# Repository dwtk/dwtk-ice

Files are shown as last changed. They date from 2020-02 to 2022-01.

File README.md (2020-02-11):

# dwtk-ice

An USB-connected In-Circuit Emulator for [dwtk](https://github.com/rafaelmartins/dwtk).

## Hardware

### Schematics

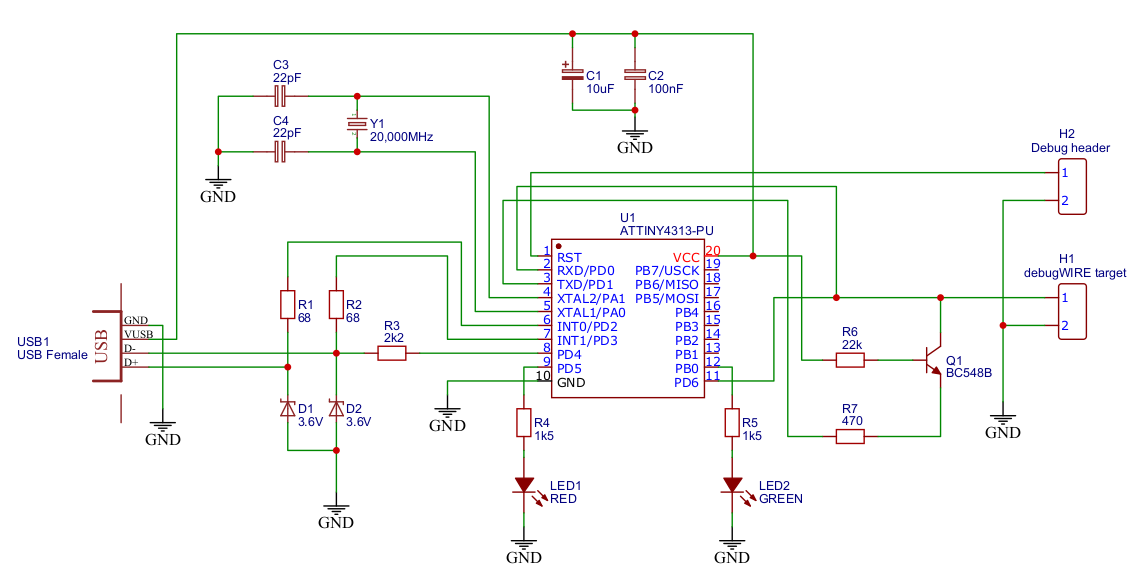
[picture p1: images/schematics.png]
dwtk-ice schematics


#### Bill of materials

ID | Description | Reichelt Item no.
-- | ----------- | -----------------
U1 | ATtiny4313 | ATTINY 4313 PU
Q1 | BC548B | BC 548B
Y1 | Crystal 20,000MHz | 20,0000-HC49U-S
D1, D2 | Zener diode 3,6V | ZF 3,6
LED1 | LED Red 5mm | LED 5MM RT
LED2 | LED Green 5mm | LED 5MM GN
C1 | Electrolytic capacitor 10uF/35V | RAD 10/35
C2 | Multi-layer ceramic capacitor 100nF | X7R-5 100N
C3, C4 | Ceramic capacitor 22pF | KERKO 22P
R1, R2 | Carbon film resistor 1/4 W, 5%, 68 Ohm| 1/4W 68
R3 | Carbon film resistor 1/4 W, 5%, 2,2K Ohm | 1/4W 2,2K
R4, R5 | Carbon film resistor 1/4 W, 5%, 1,5K Ohm | 1/4W 1,5K
R6 | Carbon film resistor 1/4 W, 5%, 22K Ohm | 1/4W 22K
R7 | Carbon film resistor 1/4 W, 5%, 470 Ohm | 1/4W 470
USB1 | USB panel socket, type A | RND 205-00660
H1 + H2 | Header pins 1x40 | SL 1X40G 2,54
&nbsp; | IC socket, 20-pin | GS 20
&nbsp; | Prototype PCB 3cm x 7cm | &nbsp;

### Prototype

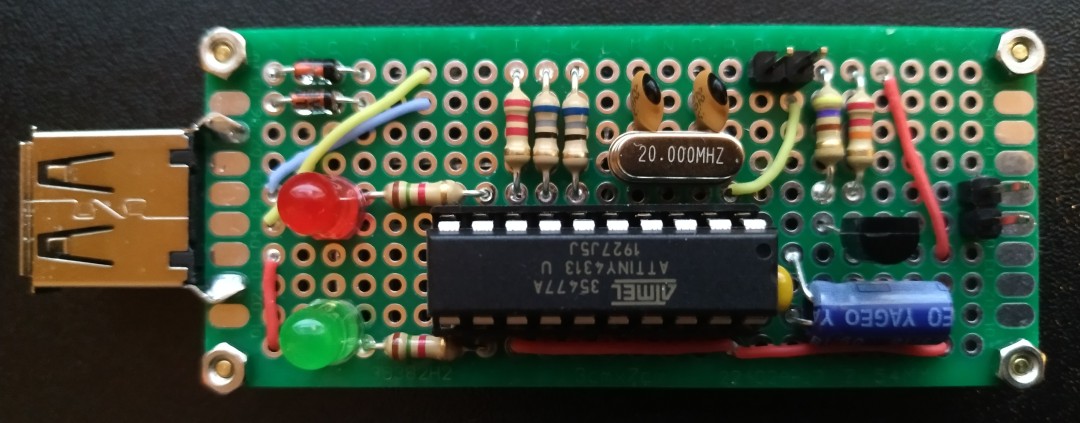
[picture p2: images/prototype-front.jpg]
dwtk-ice prototype front


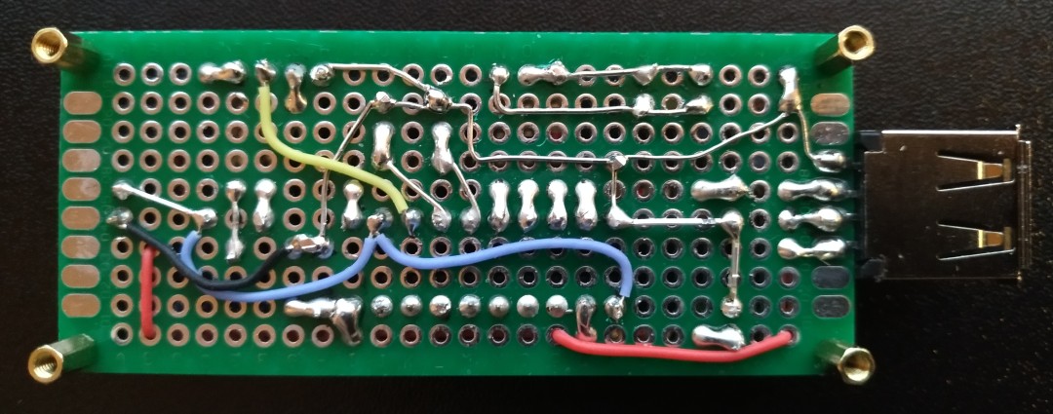
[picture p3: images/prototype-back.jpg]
dwtk-ice prototype back


### DISCLAIMER

THIS PROJECT IS PROVIDED AS IS. USE IT AT YOUR OWN RISK. THIS DEVICE IS USB CONNECTED AND MAY DAMAGE YOUR COMPUTER.

The USB connections in the schematics are there just for reference, please check the actual pinout of your connector before assembling and/or using.

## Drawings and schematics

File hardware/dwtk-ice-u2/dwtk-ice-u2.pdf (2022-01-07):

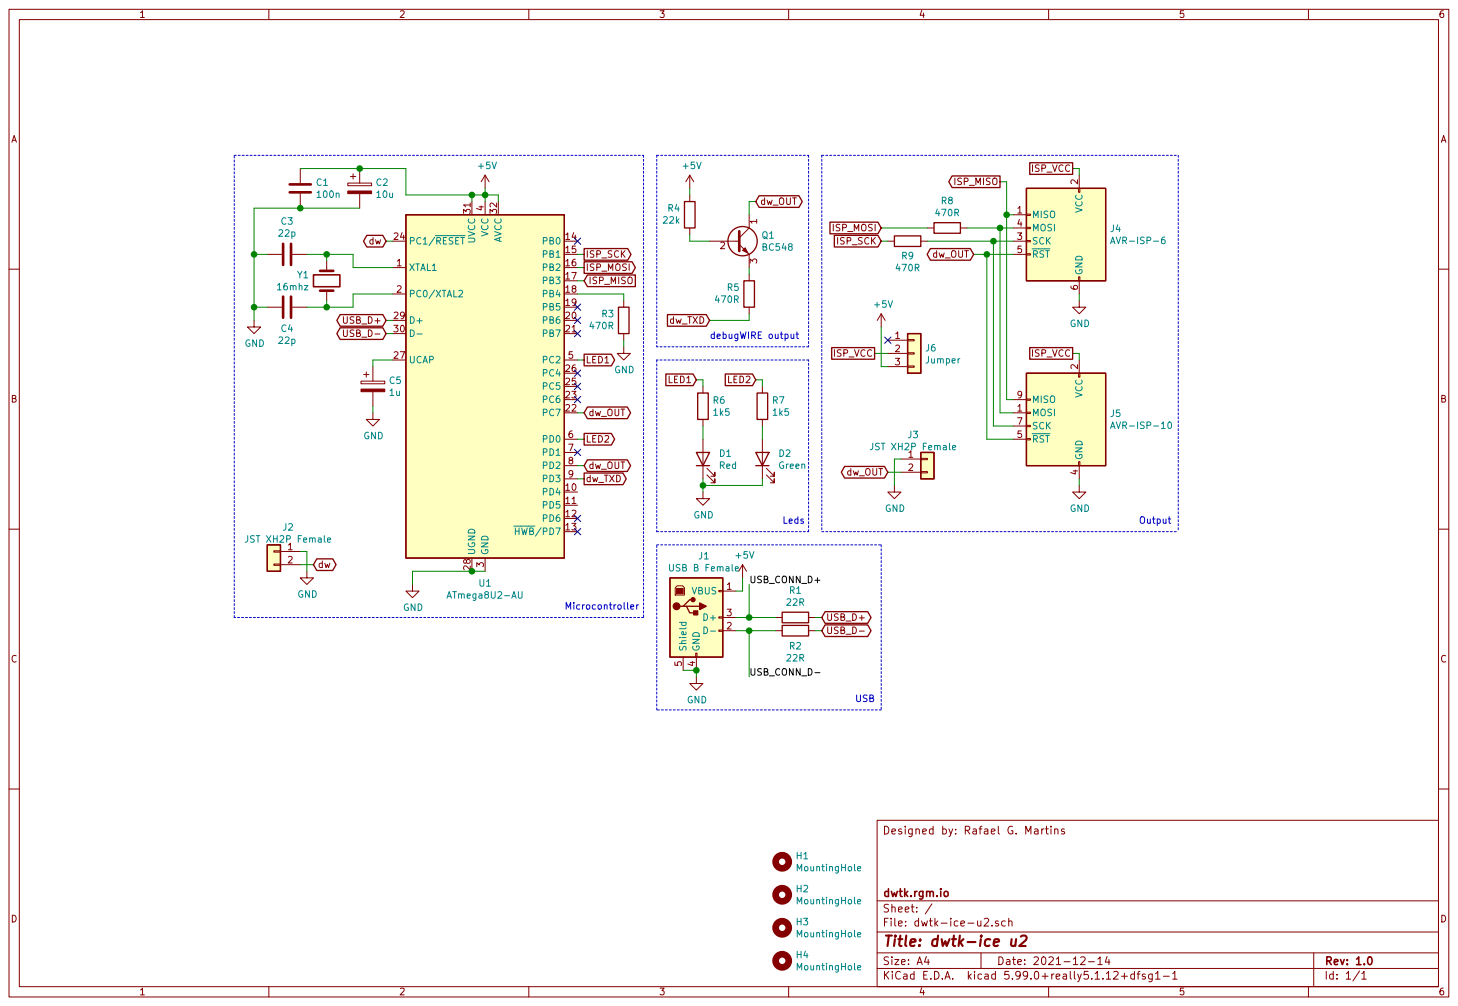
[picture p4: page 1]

2 SCK 3 MOSI 4 RST 5 GND

Designed by: Rafael G. Martins
H4MountingHole H3MountingHole H2MountingHole H1MountingHole

File: dwtk-ice-u2.sch Sheet: / dwtk.rgm.io

Id: 1/1 Title: dwtk-ice u2

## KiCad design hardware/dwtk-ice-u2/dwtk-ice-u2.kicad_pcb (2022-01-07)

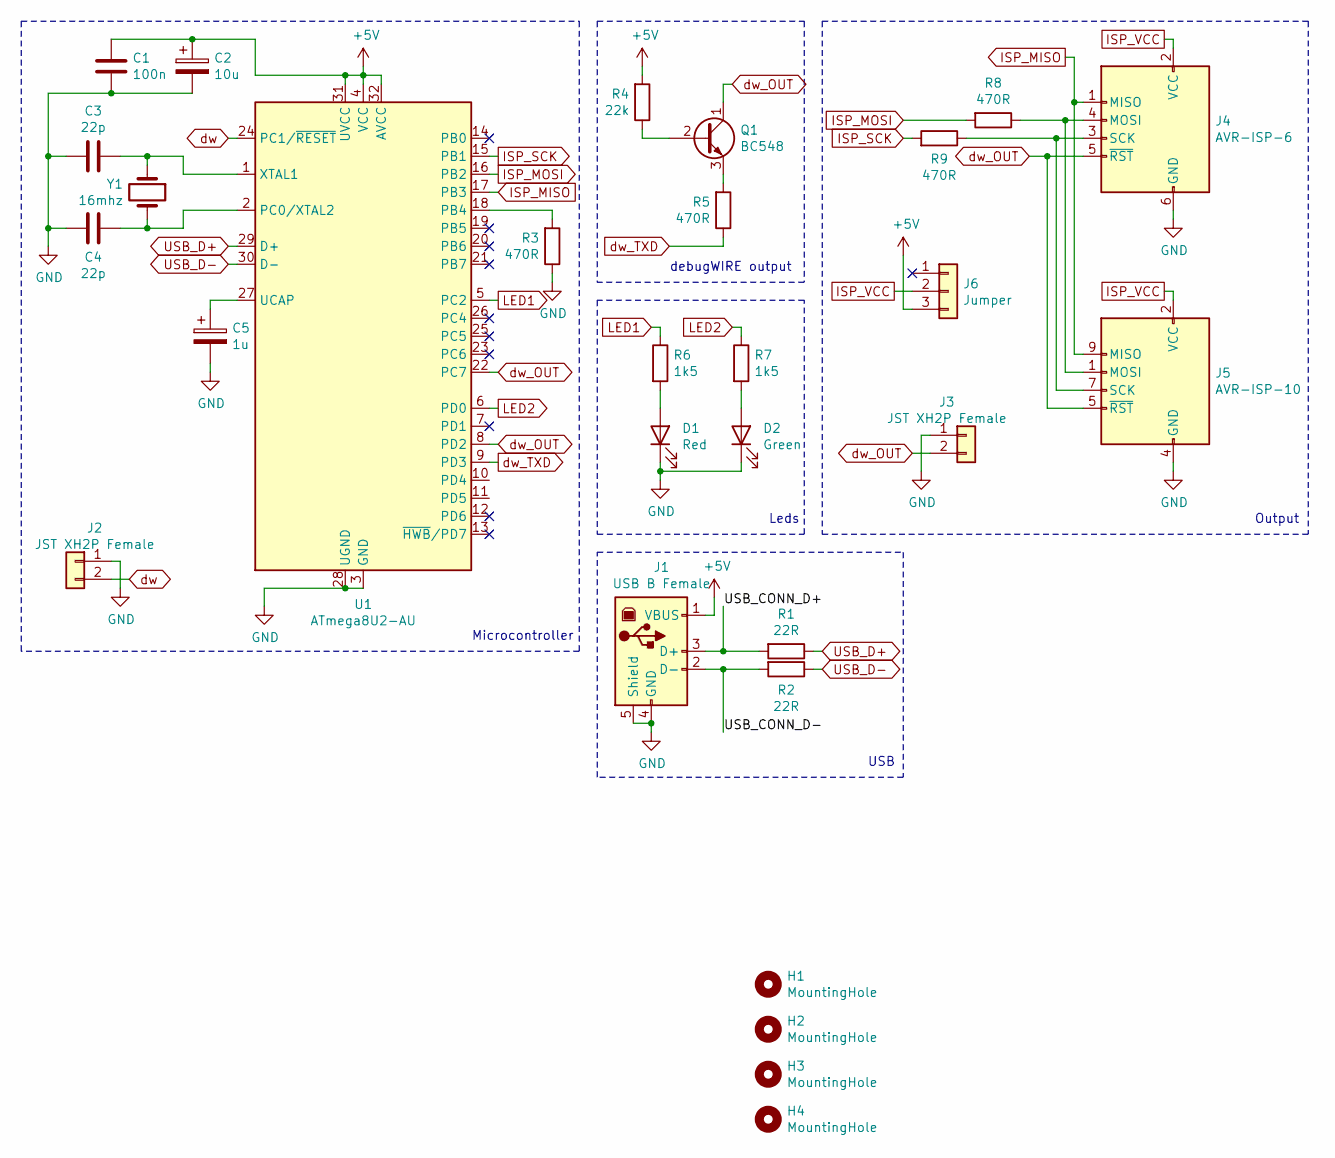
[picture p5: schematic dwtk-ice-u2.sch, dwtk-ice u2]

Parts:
C1: 100n; C_Disc_D4.3mm_W1.9mm_P5.00mm; Mouser Ref. 594-K104K15X7RF53K2
C2: 10u; CP_Radial_D5.0mm_P2.50mm; Mouser Ref. 667-ECA-1VM100I
C3, C4: 22p; C_Disc_D3.0mm_W1.6mm_P2.50mm; Mouser Ref. 594-K220J15C0GF53L2
C5: 1u; CP_Radial_D5.0mm_P2.50mm; Mouser Ref. 667-ECA-2VM010B
D1: Red; LED_D3.0mm; Mouser Ref. 604-WP710A10SEC/J3
D2: Green; LED_D3.0mm; Mouser Ref. 604-WP710A10ZGC/G
H1, H2, H3, H4: MountingHole; MountingHole_2.2mm_M2_Pad_Via
J1: USB B Female; USB_B_Lumberg_2411_02_Horizontal; Mouser Ref. 710-61400416121
J2, J3: JST XH2P Female; JST_XH_B2B-XH-A_1x02_P2.50mm_Vertical; Mouser Ref. N/A
J4: AVR-ISP-6; IDC-Header_2x03_P2.54mm_Vertical; Mouser Ref. 710-61200621621
J5: AVR-ISP-10; IDC-Header_2x05_P2.54mm_Vertical; Mouser Ref. 710-61201021621
J6: Jumper; PinHeader_1x03_P2.54mm_Vertical; Mouser Ref. 68797-236HLF
Q1: BC548; TO-92_Inline; Mouser Ref. 821-BC548B-A1
R1, R2: 22R; R_Axial_DIN0207_L6.3mm_D2.5mm_P10.16mm_Horizontal; Mouser Ref. 603-MFR-25FTF52-22R
R3, R5, R8, R9: 470R; R_Axial_DIN0207_L6.3mm_D2.5mm_P10.16mm_Horizontal; Mouser Ref. 603-MFR-25FTF52-470R
R4: 22k; R_Axial_DIN0207_L6.3mm_D2.5mm_P10.16mm_Horizontal; Mouser Ref. 603-MFR-25FTF52-22K
R6, R7: 1k5; R_Axial_DIN0207_L6.3mm_D2.5mm_P10.16mm_Horizontal; Mouser Ref. 603-MFR-25FTF52-1K5
U1: ATmega8U2-AU; TQFP-32_7x7mm_P0.8mm_LongPads; Mouser Ref. 556-ATMEGA8U2-AU
Y1: 16mhz; Crystal_HC49-U_Vertical; Mouser Ref. 815-ABL-16-B4Y

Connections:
+5V: C1.1, C2.1, J1.1 (VBUS), J6.3, R4.2, U1.4 (VCC), U1.31 (UVCC), U1.32 (AVCC)
/USB_CONN_D+: J1.3 (D+), R1.2
/USB_CONN_D-: J1.2 (D-), R2.2
GND: C1.2, C2.2, C3.2, C4.2, C5.2, D1.1 (K), D2.1 (K), J1.4 (GND), J1.5 (Shield), J2.1, J3.1, J4.6 (GND), J5.4 (GND), J5.6 (GND), J5.8 (GND), J5.10 (GND), R3.1, U1.3 (GND), U1.28 (UGND)
ISP_MISO: J4.1 (MISO), J5.9 (MISO), U1.17 (PB3)
ISP_MOSI: R8.2, U1.16 (PB2)
ISP_SCK: R9.2, U1.15 (PB1)
ISP_VCC: J4.2 (VCC), J5.2 (VCC), J6.2
LED1: R6.1, U1.5 (PC2)
LED2: R7.1, U1.6 (PD0)
unnamed: C3.1, U1.1 (XTAL1), Y1.1
unnamed: C4.1, U1.2 (PC0/XTAL2), Y1.2
unnamed: C5.1, U1.27 (UCAP)
unnamed: D1.2 (A), R6.2
unnamed: D2.2 (A), R7.2
unnamed: J4.3 (SCK), J5.7 (SCK), R9.1
unnamed: J4.4 (MOSI), J5.1 (MOSI), R8.1
unnamed: Q1.2 (B), R4.1
unnamed: Q1.3 (E), R5.2
unnamed: R3.2, U1.18 (PB4)
USB_D+: R1.1, U1.29 (D+)
USB_D-: R2.1, U1.30 (D-)
dw: J2.2, U1.24 (PC1/~RESET)
dw_OUT: J3.2, J4.5 (~RST), J5.5 (~RST), Q1.1 (C), U1.8 (PD2), U1.22 (PC7)
dw_TXD: R5.1, U1.9 (PD3)

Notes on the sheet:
Leds
Microcontroller
USB
Output
debugWIRE output

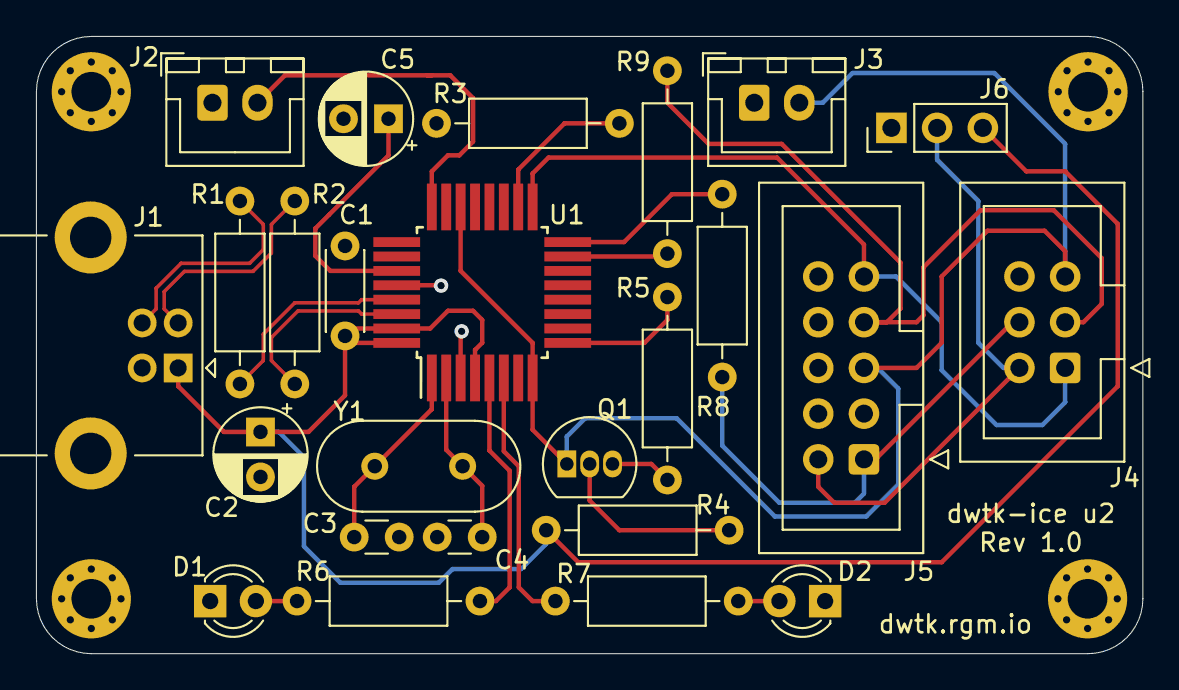
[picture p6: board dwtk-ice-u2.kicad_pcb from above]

Board: 2 copper layers, 61.5 x 34.3 mm, 29 parts (0 on the bottom side), 25 nets.

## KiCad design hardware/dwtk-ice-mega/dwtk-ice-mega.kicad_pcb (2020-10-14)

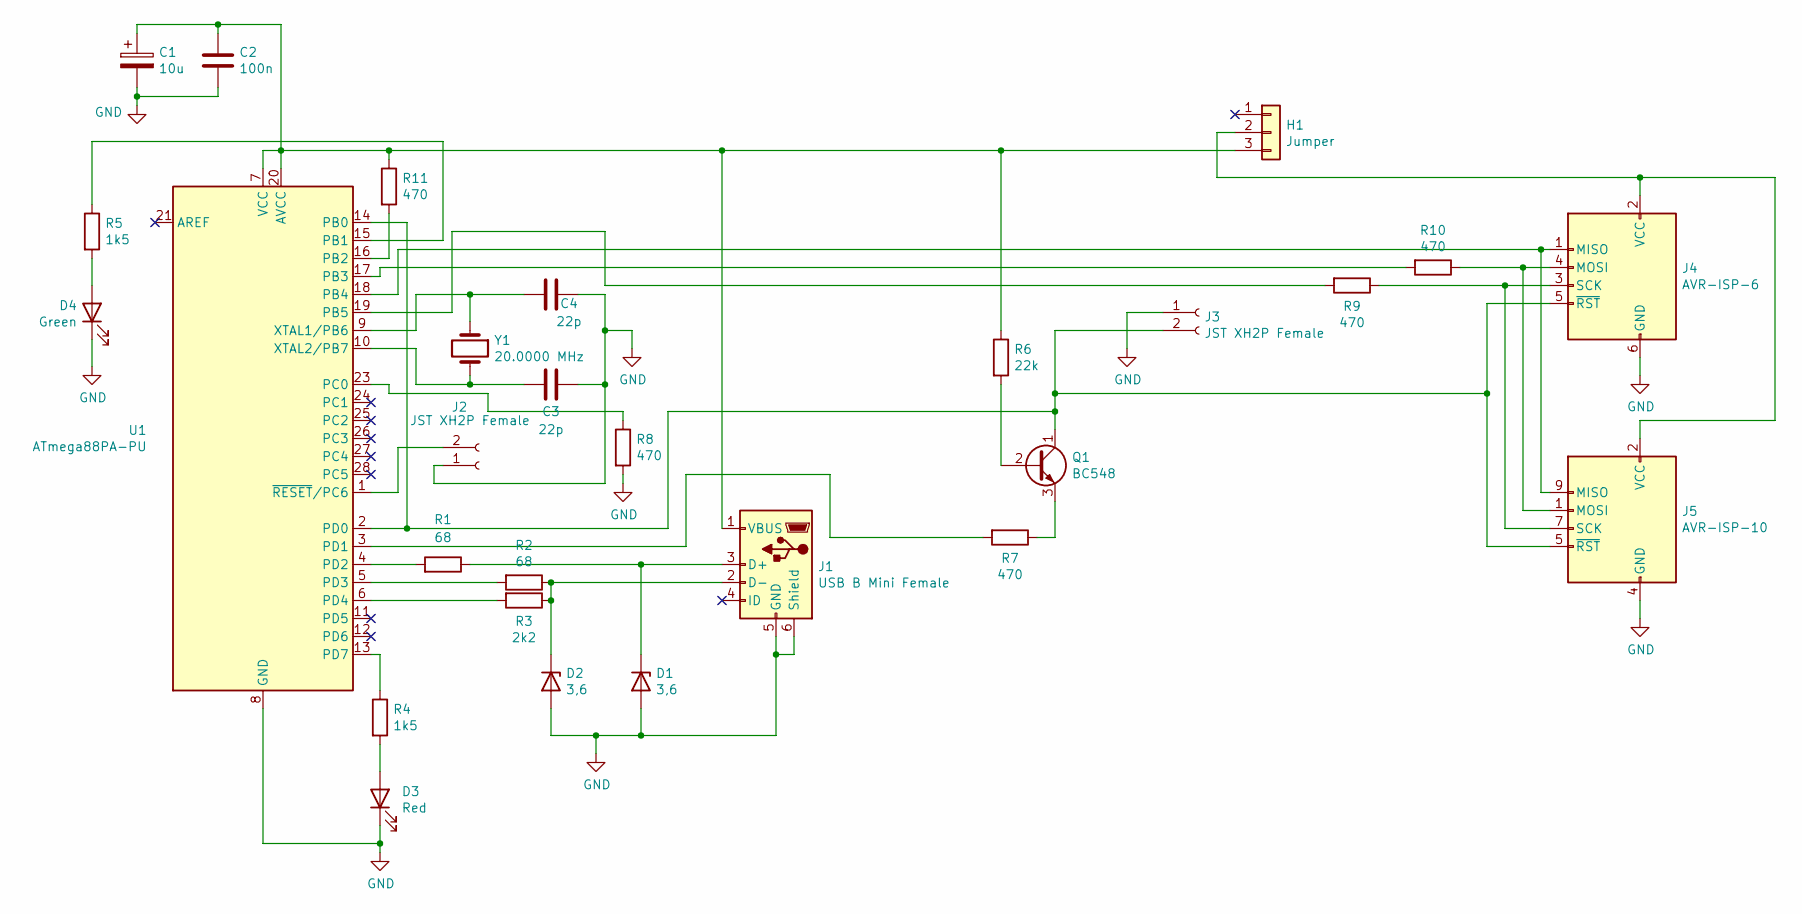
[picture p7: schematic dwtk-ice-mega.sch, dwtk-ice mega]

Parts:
C1: 10u; CP_Radial_D4.0mm_P2.00mm
C2: 100n; C_Disc_D3.0mm_W1.6mm_P2.50mm
C3, C4: 22p; C_Disc_D3.0mm_W1.6mm_P2.50mm
D1, D2: 3,6; D_DO-35_SOD27_P7.62mm_Horizontal
D3: Red; LED_D3.0mm
D4: Green; LED_D3.0mm
H1: Jumper; PinHeader_1x03_P2.54mm_Vertical
J1: USB B Mini Female; RND_205-00862
J2, J3: JST XH2P Female; JST_XH_B2B-XH-A_1x02_P2.50mm_Vertical
J4: AVR-ISP-6; IDC-Header_2x03_P2.54mm_Vertical
J5: AVR-ISP-10; IDC-Header_2x05_P2.54mm_Vertical
Q1: BC548; TO-92_Inline
R1, R2: 68; R_Axial_DIN0207_L6.3mm_D2.5mm_P10.16mm_Horizontal
R3: 2k2; R_Axial_DIN0207_L6.3mm_D2.5mm_P10.16mm_Horizontal
R4, R5: 1k5; R_Axial_DIN0207_L6.3mm_D2.5mm_P10.16mm_Horizontal
R6: 22k; R_Axial_DIN0207_L6.3mm_D2.5mm_P10.16mm_Horizontal
R7, R8, R9, R10, R11: 470; R_Axial_DIN0207_L6.3mm_D2.5mm_P10.16mm_Horizontal
U1: ATmega88PA-PU; DIP-28_W7.62mm
Y1: 20.0000 MHz; Crystal_HC49-U_Vertical

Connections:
GND: C1.2, C2.2, C3.1, C4.1, D1.2 (A), D2.2 (A), D3.1 (K), D4.1 (K), J1.5 (GND), J1.6 (Shield), J2.1, J3.1, J4.6 (GND), J5.4 (GND), J5.6 (GND), J5.8 (GND), J5.10 (GND), R8.2, U1.8 (GND), U1.22 (GND)
unnamed: C1.1, C2.1, H1.3, J1.1 (VBUS), R6.1, R11.1, U1.7 (VCC), U1.20 (AVCC)
unnamed: C3.2, U1.10 (XTAL2/PB7), Y1.2
unnamed: C4.2, U1.9 (XTAL1/PB6), Y1.1
unnamed: D1.1 (K), J1.3 (D+), R1.1
unnamed: D2.1 (K), J1.2 (D-), R2.1, R3.1
unnamed: D3.2 (A), R4.2
unnamed: D4.2 (A), R5.2
unnamed: H1.2, J4.2 (VCC), J5.2 (VCC)
unnamed: J2.2, U1.1 (~RESET~/PC6)
unnamed: J3.2, J4.5 (~RST), J5.5 (~RST), Q1.1 (C), U1.2 (PD0), U1.14 (PB0)
unnamed: J4.1 (MISO), J5.9 (MISO), U1.18 (PB4)
unnamed: J4.3 (SCK), J5.7 (SCK), R9.1
unnamed: J4.4 (MOSI), J5.1 (MOSI), R10.1
unnamed: Q1.2 (B), R6.2
unnamed: Q1.3 (E), R7.1
unnamed: R1.2, U1.4 (PD2)
unnamed: R2.2, U1.5 (PD3)
unnamed: R3.2, U1.6 (PD4)
unnamed: R4.1, U1.13 (PD7)
unnamed: R5.1, U1.15 (PB1)
unnamed: R7.2, U1.3 (PD1)
unnamed: R8.1, U1.23 (PC0)
unnamed: R9.2, U1.19 (PB5)
unnamed: R10.2, U1.17 (PB3)
unnamed: R11.2, U1.16 (PB2)

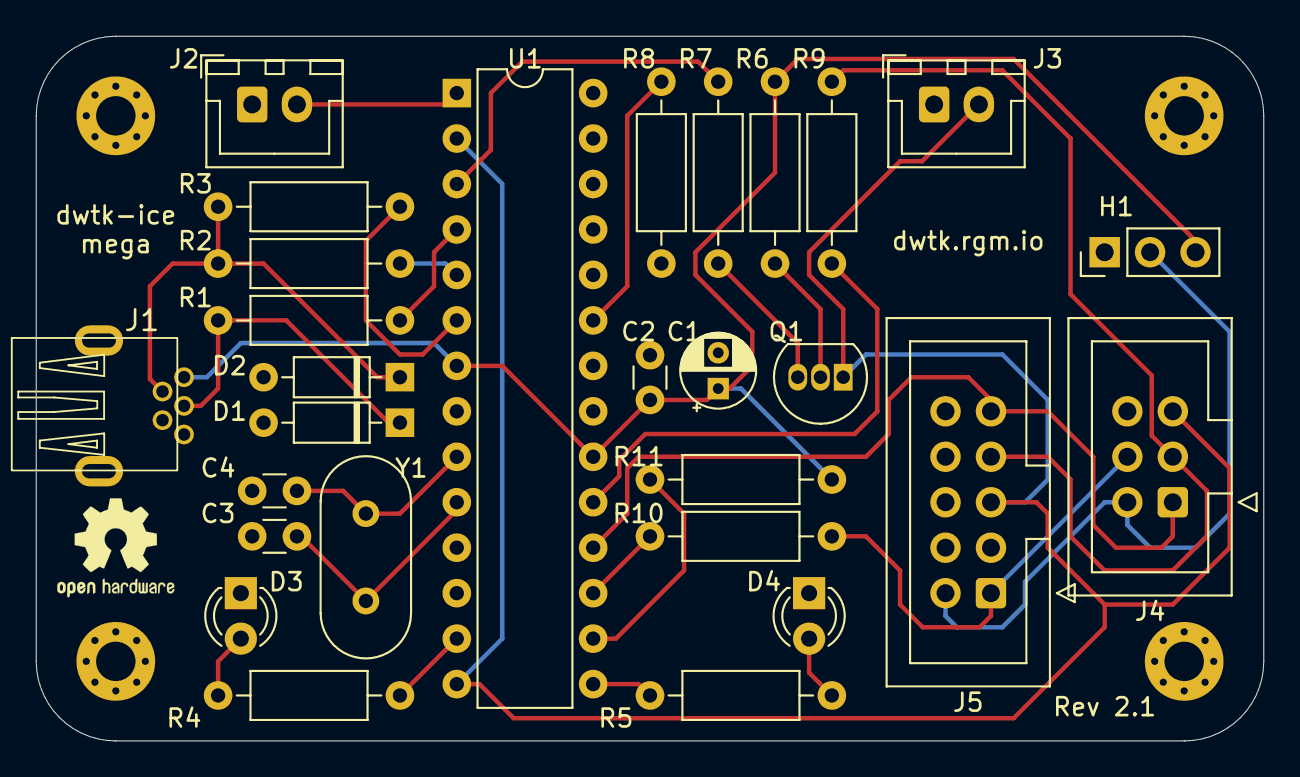
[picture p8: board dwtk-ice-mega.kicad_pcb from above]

Board: 2 copper layers, 68.6 x 39.4 mm, 28 parts (0 on the bottom side), 26 nets.

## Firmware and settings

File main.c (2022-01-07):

/*
 * dwtk-ice: An USB-connected In-Circuit Emulator for dwtk.
 * Copyright (C) 2019 Rafael G. Martins <rafael@rafaelmartins.eng.br>
 *
 * This program can be distributed under the terms of the GPL-2 License.
 * See the file COPYING.
 */

#include <stdbool.h>
#include <avr/eeprom.h>
#include <avr/interrupt.h>
#include <avr/io.h>
#include <avr/wdt.h>
#include <util/delay.h>
#include "bits.h"
#include "usart.h"

#if defined(__AVR_ATmega8U2__) || defined(__AVR_ATmega16U2__) || defined(__AVR_ATmega32U2__)
#include "usb-u2/usb-u2.h"
#define BUILD_WITH_USB_U2 1

#define USBRQ_DIR_MASK USB_U2_REQ_DIR_MASK
#define USBRQ_DIR_HOST_TO_DEVICE USB_U2_REQ_DIR_HOST_TO_DEVICE
#define USB_NO_MSG 0xff

typedef uint8_t usbMsgLen_t;
typedef uint8_t uchar;

typedef union {
    uint16_t word;
    uint8_t  bytes[2];
} usbWord_t;

typedef struct {
    uint8_t   bmRequestType;
    uint8_t   bRequest;
    usbWord_t wValue;
    usbWord_t wIndex;
    usbWord_t wLength;
} usbRequest_t;

static uint8_t *usbMsgPtr;
#else
#include "usbdrv/usbdrv.h"
#define BUILD_WITH_VUSB 1

int usbDescriptorStringSerialNumber[9];
#endif

#define FREQ_MHZ (F_CPU/1000000)

#define DW_SPMEN  (1 << 0)
#define DW_PGERS  (1 << 1)
#define DW_PGWRT  (1 << 2)
#define DW_RFLB   (1 << 3)
#define DW_CTPB   (1 << 4)
#define DW_RWWSRE (1 << 4)
#define DW_RWWSB  (1 << 6)

#define DW_SPMCSR 0x37

// opcode: 1001 000d dddd 0100 - Z
// opcode: 1001 000d dddd 0101 - Z+
#define DW_LPM(reg, inc)  0b1001000000000100 | \
                          ((0b11111 & reg) << 4) | \
                          (0b1 & inc)

// opcode: 1001 0101 1110 1000
#define DW_SPM()          0b1001010111101000

// opcode: 1001 0110 KKdd KKKK
#define DW_ADIW(reg, val) 0b1001011000000000 | \
                          ((0b110000 & val) << 2) | \
                          ((0b110 & (reg - 24)) << 3) | \
                          (0b1111 & val)

// opcode: 1011 1AAr rrrr AAAA
#define DW_OUT(addr, reg) 0b1011100000000000 | \
                          ((0b110000 & addr) << 5) | \
                          ((0b11111 & reg) << 4) | \
                          (0b1111 & addr)

// opcode: 1011 0AAd dddd AAAA
#define DW_IN(addr, reg)  0b1011000000000000 | \
                          ((0b110000 & addr) << 5) | \
                          ((0b11111 & reg) << 4) | \
                          (0b1111 & addr)

#define CAP_DW  (1 << 0)
#define CAP_SPI (1 << 1)

typedef enum {
    CMD_GET_ERROR = 1,
    CMD_GET_CAPABILITIES,

    CMD_SPI_PGM_ENABLE = 0x20,
    CMD_SPI_PGM_DISABLE,
    CMD_SPI_COMMAND,
    CMD_SPI_RESET,

    CMD_DETECT_BAUDRATE = 0x40,
    CMD_GET_BAUDRATE,
    CMD_DISABLE,
    CMD_RESET,
    CMD_READ_SIGNATURE,
    CMD_SEND_BREAK,
    CMD_RECV_BREAK,
    CMD_GO,
    CMD_STEP,
    CMD_CONTINUE,
    CMD_WAIT,
    CMD_WRITE_INSTRUCTION,
    CMD_SET_PC,
    CMD_GET_PC,
    CMD_REGISTERS,
    CMD_SRAM,
    CMD_READ_FLASH,
    CMD_WRITE_FLASH_PAGE,
    CMD_ERASE_FLASH_PAGE,
    CMD_READ_FUSES,
} usb_command_t;

typedef enum {
    ERR_NONE = 0,
    ERR_UNSUPPORTED,

    ERR_SPI_PGM_ENABLE = 0x20,
    ERR_SPI_ECHO_MISMATCH,

    ERR_BAUDRATE_DETECTION = 0x40,
    ERR_ECHO_MISMATCH,
    ERR_BREAK_MISMATCH,
    ERR_TOO_LARGE,
} error_type_t;

static bool after_break = false;
static bool detect_baudrate = false;
static bool mode_spi = false;
static uint16_t flash_page_start = 0;
static uint16_t pulse_width = 0;
static uint16_t request_len = 0;
static uint16_t remaining = 0;
static uint16_t rww_start = 0;
static uint16_t ubrr = 0xffff;
static usb_command_t cmd = 0;

// this is defined by the biggest flash page size we support, that is 128 bytes.
// it is also limited by the SRAM size of the ATtiny4313. if we want to support
// any device with bigger flash page size, we will need to implement partial
// read/write from the host. This is kinda tricky, specially for reads, because
// the devices won't wait too long for data reads.
static uint8_t alloc[131] = {
    ERR_NONE,
};
// first 3 bytes are for error reporting.
static uint8_t *err = alloc;
static uint8_t *buf = alloc + 3;


static void
recv_to_buffer(uint8_t len)
{
    if (err[0] != ERR_NONE) {
        return;
    }
    if (len > 128) {
        err[0] = ERR_TOO_LARGE;
        return;
    }
    for (uint8_t i = 0; i < len; i++) {
        buf[i] = usart_recv_byte();
    }
}


static void
recv_break(void)
{
    if (err[0] != ERR_NONE) {
        return;
    }
    wdt_reset();
    uint8_t c = usart_recv_break();
    if (0x55 != c) {
        err[0] = ERR_BREAK_MISMATCH;
        err[1] = c;
        return;
    }
    after_break = true;
}


static void
send_break(void)
{
    if (err[0] != ERR_NONE) {
        return;
    }
    usart_send_break(pulse_width ? pulse_width : 3000);  // 3000 ticks * (1/20000000) = 150us
    recv_break();
}


static void
send_byte(uint8_t b)
{
    if (err[0] != ERR_NONE) {
        return;
    }
    usart_send_byte(b);
    uint8_t c = usart_recv_byte();
    if (b != c) {
        err[0] = ERR_ECHO_MISMATCH;
        err[1] = b;
        err[2] = c;
    }
}


static void
set_pc(uint16_t pc)
{
    send_byte(0xd0);
    send_byte(pc >> 8);
    send_byte(pc);
}


static void
registers(uint8_t start, uint8_t len, bool write)
{
    send_byte(0x66);
    set_pc(start);
    send_byte(0xd1);
    send_byte(0x00);
    send_byte(start + len);
    send_byte(0xc2);
    send_byte(write ? 0x05 : 0x01);
    send_byte(0x20);
}


static void
write_instruction(uint16_t inst)
{
    send_byte(0x64);
    send_byte(0xd2);
    send_byte(inst >> 8);
    send_byte(inst);
    send_byte(0x23);
}


static void
wait_spmcsr(uint8_t mask)
{
    wdt_reset();
    send_break();
    for (uint8_t i = 0; i < 0xff; i++) {
        write_instruction(DW_IN(DW_SPMCSR, 29));
        _delay_ms(5);  // FIXME
        registers(29, 1, false);
        if ((mask & usart_recv_byte()) == 0) {
            return;
        }
    }
}


static void
spm(void)
{
    write_instruction(DW_OUT(DW_SPMCSR, 29));
    set_pc(rww_start);
    write_instruction(DW_SPM());
}


static void
erase_flash_page(uint16_t start, bool set_start)
{
    registers(29, set_start ? 3 : 1, true);
    send_byte(DW_PGERS | DW_SPMEN);
    if (set_start) {
        send_byte(start);
        send_byte(start >> 8);
    }
    spm();
    wait_spmcsr(DW_SPMEN);
}


static uint16_t
detect_pulse_width(void)
{
    uint16_t rv = 0;

    TCCR1A = 0;
    TCCR1B = (1 << ICNC1) | (1 << CS10);
    TIFR = (1 << TOV1);

    usart_send_break(3000);  // 3000 ticks * (1/20000000) = 150us
    while (!PIN_TEST(P_TXD));

    TCNT1 = 0;
    TIFR = (1 << TOV1) | (1 << ICF1);
    TCCR1B |= (1 << ICES1);
    cli();
    while (!(TIFR & ((1 << ICF1) | (1 << TOV1))));
    rv = ICR1;
    if (TIFR & (1 << TOV1)) {
        sei();
        TCCR1B = 0;
        err[0] = ERR_BAUDRATE_DETECTION;
        return 0;
    }

    TIFR = (1 << ICF1);
    TCCR1B &= ~(1 << ICES1);
    while (!(TIFR & ((1 << ICF1) | (1 << TOV1))));
    sei();
    rv = ICR1 - rv;
    if (TIFR & (1 << TOV1)) {
        TCCR1B = 0;
        err[0] = ERR_BAUDRATE_DETECTION;
        return 0;
    }

    TCCR1B = 0;
    return rv;
}


static void
sram_flash(uint16_t addr, uint8_t d0, uint16_t d1, uint8_t c2)
{
    registers(30, 2, true);
    send_byte(addr);
    send_byte(addr >> 8);
    send_byte(0x66);
    set_pc(d0);
    send_byte(0xd1);
    send_byte(d1 >> 8);
    send_byte(d1);
    send_byte(0xc2);
    send_byte(c2);
    send_byte(0x20);
}


static uint8_t
spi(uint8_t c)
{
    if (err[0] != ERR_NONE) {
        return 0;
    }
#if defined(USIDR)
    USIDR = c;
    USISR = (1 << USIOIF);
    while (!(USISR & (1 << USIOIF))) {
        USICR = (1 << USIWM0) | (1 << USICS1) | (1 << USICLK) | (1 << USITC);
        _delay_us(10);
    }
    return USIDR;
#elif defined(SPDR)
    SPDR = c;
    while(!(SPSR & (1 << SPIF)));
    return SPDR;
#else
#   error "No valid SPI implementation found."
#endif
}


static void
spi_reset(void)
{
    PORT_SET(P_TXD);
    _delay_us(10);
    PORT_CLEAR(P_TXD);
    _delay_us(100);
    PORT_SET(P_TXD);
}


usbMsgLen_t
usbFunctionSetup(uchar data[8])
{
    usbRequest_t *rq = (void*) data;
    bool write = (rq->bmRequestType & USBRQ_DIR_MASK) == USBRQ_DIR_HOST_TO_DEVICE;
    usbMsgLen_t rv = 3;  // err, always return err + buf unless USB_NO_MSG

    cmd = rq->bRequest;

    switch (cmd) {
        // these are the commands that support reading/writing
        case CMD_REGISTERS:
        case CMD_SRAM:
            break;

        // these are the commands that support only writing
        case CMD_WRITE_FLASH_PAGE:
            if (!write) {
                return 0;
            }
            break;

        // everything else supports only read
        default:
            if (write) {
                return 0;
            }
    }

    if (cmd != CMD_GET_ERROR) {
        err[0] = ERR_NONE;
        err[1] = 0;
        err[2] = 0;
    }

    request_len = rq->wLength.word;
    if (request_len > 0 && !write) {
        request_len -= 3;  // size of err isn't part of request
    }
    remaining = request_len;

    if (cmd >= 0x20) {
        if (cmd < 0x40) {  // SPI
            if (!mode_spi) {
                usart_clear();
                DDR_SET(P_DO);
                DDR_SET(P_USCK);
                DDR_SET(P_TXD);
#ifdef SPCR
                SPCR = (1 << SPE) | (1 << MSTR) | (1 << SPR0) | (1 << SPR1);
#else
                PORT_CLEAR(P_DO);
                PORT_CLEAR(P_USCK);
                PORT_CLEAR(P_TXD);
#endif
                mode_spi = true;
            }
        }
        else {  // debugWIRE
            if (mode_spi) {
#ifdef SPCR
                SPCR = 0;
#endif
                DDR_CLEAR(P_DO);
                DDR_CLEAR(P_USCK);
                DDR_CLEAR(P_TXD);
                if (ubrr != 0xffff) {
                    usart_init(ubrr);
                }
                mode_spi = false;
            }
        }
    }

    switch (cmd) {
        case CMD_GET_ERROR: {
            // nothing to do, error is already set.
            break;
        }

        case CMD_GET_CAPABILITIES: {
            buf[0] = CAP_DW | (PIN_TEST(P_CAP_SPI) ? 0x00 : CAP_SPI);
            rv++;
            break;
        }

        case CMD_SPI_PGM_ENABLE: {
            // reset
            spi_reset();
            PORT_CLEAR(P_TXD);
            _delay_ms(30);

            // first try
            buf[0] = spi(0xac);
            buf[1] = spi(0x53);
            buf[2] = spi(0);
            buf[3] = spi(0);
            rv += 4;
            if (0x53 == buf[2]) {
                break;
            }

            // second try
            buf[0] = spi(0xac);
            buf[1] = spi(0x53);
            buf[2] = spi(0);
            buf[3] = spi(0);
            if (0x53 != buf[2]) {
                err[0] = ERR_SPI_PGM_ENABLE;
            }

            break;
        }

        case CMD_SPI_PGM_DISABLE: {
            PORT_SET(P_TXD);
            break;
        }

        case CMD_SPI_COMMAND: {
            buf[0] = spi(rq->wValue.word >> 8);
            buf[1] = spi(rq->wValue.word);
            buf[2] = spi(rq->wIndex.word >> 8);
            buf[3] = spi(rq->wIndex.word);
            if (((uint8_t) rq->wValue.word) != buf[2]) {
                err[0] = ERR_SPI_ECHO_MISMATCH;
                err[1] = rq->wValue.word;
                err[2] = buf[2];
            }
            rv += 4;
            break;
        }

        case CMD_SPI_RESET: {
            spi_reset();
            break;
        }

        case CMD_DETECT_BAUDRATE: {
            detect_baudrate = true;
            break;
        }

        case CMD_GET_BAUDRATE: {
            buf[0] = FREQ_MHZ;
            buf[1] = 8;
            buf[2] = pulse_width >> 8;
            buf[3] = pulse_width;
            buf[4] = ubrr >> 8;
            buf[5] = ubrr;
            rv += 6;
            break;
        }

        case CMD_DISABLE: {
            send_byte(0x06);
            break;
        }

        case CMD_RESET: {
            send_break();
            send_byte(0x07);
            recv_break();
            break;
        }

        case CMD_READ_SIGNATURE: {
            send_byte(0xf3);
            buf[0] = usart_recv_byte();
            buf[1] = usart_recv_byte();
            rv += 2;
            break;
        }

        case CMD_SEND_BREAK: {
            send_break();
            break;
        }

        case CMD_RECV_BREAK: {
            recv_break();
            break;
        }

        case CMD_GO: {
            send_byte(0x40);
            send_byte(0x30);
            break;
        }

        case CMD_STEP: {
            send_byte(0x60);
            send_byte(0x31);
            recv_break();
            break;
        }

        case CMD_CONTINUE: {
            // idx: byte 0 -> hw bp set
            //      byte 1 -> timers
            uint8_t t = 0x60;
            if (rq->wIndex.word & (1 << 0)) {
                uint16_t bp = rq->wValue.word / 2;
                t++;
                send_byte(0xd1);
                send_byte(bp >> 8);
                send_byte(bp);
            }
            if (rq->wIndex.word & (1 << 1)) {
                t -= 0x20;
            }
            send_byte(t);
            send_byte(0x30);
            break;
        }

        case CMD_WAIT: {
            buf[0] = (UCSRA & (1 << RXC)) ? 0xff : 0;
            rv++;
            break;
        }

        case CMD_WRITE_INSTRUCTION: {
            write_instruction(rq->wValue.word);
            break;
        }

        case CMD_SET_PC: {
            set_pc(rq->wValue.word / 2);
            after_break = false;
            break;
        }

        case CMD_GET_PC: {
            send_byte(0xf0);
            uint16_t b = usart_recv_byte() << 8;
            b |= usart_recv_byte();
            if (after_break) {
                b--;
                after_break = false;
            }
            b *= 2;
            buf[0] = b >> 8;
            buf[1] = b;
            rv += 2;
            break;
        }

        case CMD_REGISTERS: {
            registers(rq->wValue.word, request_len, write);
            if (write) {
                return USB_NO_MSG;
            }
            recv_to_buffer(request_len);
            rv += request_len;
            break;
        }

        case CMD_SRAM: {
            uint16_t l = request_len * 2;
            if (write) {
                l++;
            }
            sram_flash(rq->wValue.word, write ? 0x01 : 0x00, l, write ? 0x04 : 0x00);
            if (write) {
                return USB_NO_MSG;
            }
            recv_to_buffer(request_len);
            rv += request_len;
            break;
        }

        case CMD_READ_FLASH: {
            uint16_t l = request_len * 2;
            sram_flash(rq->wValue.word, 0x00, l, 0x02);
            recv_to_buffer(request_len);
            rv += request_len;
            break;
        }

        case CMD_WRITE_FLASH_PAGE: {
            rww_start = rq->wIndex.word / 2;
            registers(29, 3, true);
            send_byte(DW_CTPB | DW_SPMEN);
            send_byte(rq->wValue.word);
            send_byte(rq->wValue.word >> 8);
            spm();
            send_break();

            erase_flash_page(0, false);

            registers(29, 1, true);
            send_byte(DW_SPMEN);

            flash_page_start = rq->wValue.word;
            return USB_NO_MSG;
        }

        case CMD_ERASE_FLASH_PAGE: {
            rww_start = rq->wIndex.word / 2;
            erase_flash_page(rq->wValue.word, true);
            break;
        }

        case CMD_READ_FUSES: {
#if defined(__AVR_ATtiny4313__) && defined(DEBUG)
            err[0] = ERR_UNSUPPORTED;
#else
            registers(30, 2, true);
            send_byte(0x00);
            send_byte(0x00);
            for (uint8_t i = 0; i < 4; i++) {
                registers(29, 1, true);
                send_byte(DW_RFLB | DW_SPMEN);
                write_instruction(DW_OUT(DW_SPMCSR, 29));
                write_instruction(DW_LPM(28, true));
                registers(28, 1, false);
                buf[i] = usart_recv_byte();
            }
            rv += 4;
#endif
            break;
        }
    }

    usbMsgPtr = alloc;

    return rv;
}


static void
func_write(void)
{
    wdt_reset();

    switch (cmd) {
        case CMD_REGISTERS:
        case CMD_SRAM: {
            uint8_t i = 0;
            wdt_reset();
            while (i < request_len) {
                send_byte(buf[i++]);
            }
            break;
        }

        case CMD_WRITE_FLASH_PAGE: {
            uint8_t i = 0;
            while (i < request_len) {
                wdt_reset();
                registers(0, 2, true);
                send_byte(buf[i++]);
                send_byte(buf[i++]);
                spm();
                write_instruction(DW_ADIW(30, 2));
            }

            wdt_reset();
            registers(29, 3, true);
            send_byte(DW_PGWRT | DW_SPMEN);
            send_byte(flash_page_start);
            send_byte(flash_page_start >> 8);
            spm();
            wait_spmcsr(DW_SPMEN);

            if (rww_start) {
                registers(29, 1, true);
                send_byte(DW_RWWSRE | DW_SPMEN);
                spm();
                wait_spmcsr(DW_RWWSB);
            }

            break;
        }

        default:
            break;
    }
}


uchar
usbFunctionWrite(uchar *data, uchar len)
{
    for (uint8_t i = 0; i < len && remaining; i++, remaining--) {
        buf[request_len - remaining] = data[i];
    }

    if (remaining) {
        return 0;
    }

    func_write();
    return 1;
}


#ifdef BUILD_WITH_USB_U2
void
usb_u2_control_vendor_cb(const usb_u2_control_request_t *req)
{
    PORT_SET(P_LEDG);

    uint8_t l = usbFunctionSetup((uint8_t*) req);
    if (l == USB_NO_MSG) {
        if ((req->bmRequestType & USB_U2_REQ_DIR_MASK) == USB_U2_REQ_DIR_HOST_TO_DEVICE) {
            usb_u2_control_out(buf, request_len);
            func_write();
            usb_u2_control_out_status();
        }
        return;
    }

    usb_u2_control_in(usbMsgPtr, l, false);
}


void
usb_u2_set_address_hook_cb(uint8_t addr)
{
    (void) addr;
    PORT_SET(P_LEDR);
}


void
usb_u2_reset_hook_cb(void)
{
    PORT_CLEAR(P_LEDR);
}
#endif


#ifdef BUILD_WITH_VUSB
static char
byte2hex(uint8_t v)
{
    return v > 9 ? v - 10 + 'a' : v + '0';
}
#endif


int
main(void)
{
    wdt_enable(WDTO_2S);

#ifdef BUILD_WITH_VUSB
    uint32_t d = eeprom_read_dword(0);
    usbDescriptorStringSerialNumber[0] = USB_STRING_DESCRIPTOR_HEADER(8);
    for (uint8_t i = 0; i < 8; i++) {
        usbDescriptorStringSerialNumber[i % 2 ? i : i + 2] = byte2hex((d >> (4 * i)) & 0xf);
    }
#endif

    DDR_SET(P_LEDG);
    DDR_SET(P_LEDR);
    DDR_CLEAR(P_CAP_SPI);
    PORT_SET(P_CAP_SPI);

#ifdef P_SS
    // devices with SPI peripheral need SS set high to enable master mode.
    // old dwtk-ice-mega designs have a pull up resistor, but doing that by
    // software is a better idea in this case.
    DDR_CLEAR(P_SS);
    PORT_SET(P_SS);
#endif

#ifdef BUILD_WITH_USB_U2
    usb_u2_init();
#endif

#ifdef BUILD_WITH_VUSB
    usbInit();
    usbDeviceDisconnect();

    wdt_reset();
    uint8_t i = 0xff;
    while (i--) {
        _delay_ms(1);
    }
    usbDeviceConnect();
#endif

    sei();

    for (;;) {
        wdt_reset();
#ifdef BUILD_WITH_USB_U2
        usb_u2_task();
#endif
#ifdef BUILD_WITH_VUSB
        usbPoll();
#endif
        PORT_CLEAR(P_LEDG);
        if (detect_baudrate) {
            detect_baudrate = false;
            usart_clear();
            pulse_width = detect_pulse_width();
            if (err[0] == ERR_NONE) {
                ubrr = (pulse_width - 4) / 8;
                usart_init(ubrr);
                send_break();
            }
        }
    }

    return 0;
}

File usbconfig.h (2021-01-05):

/* Name: usbconfig.h
 * Project: V-USB, virtual USB port for Atmel's(r) AVR(r) microcontrollers
 * Author: Christian Starkjohann
 * Creation Date: 2005-04-01
 * Tabsize: 4
 * Copyright: (c) 2005 by OBJECTIVE DEVELOPMENT Software GmbH
 * License: GNU GPL v2 (see License.txt), GNU GPL v3 or proprietary (CommercialLicense.txt)
 */

#ifndef __usbconfig_h_included__
#define __usbconfig_h_included__

#include "bits.h"

/*
General Description:
This file is an example configuration (with inline documentation) for the USB
driver. It configures V-USB for USB D+ connected to Port D bit 2 (which is
also hardware interrupt 0 on many devices) and USB D- to Port D bit 4. You may
wire the lines to any other port, as long as D+ is also wired to INT0 (or any
other hardware interrupt, as long as it is the highest level interrupt, see
section at the end of this file).
+ To create your own usbconfig.h file, copy this file to your project's
+ firmware source directory) and rename it to "usbconfig.h".
+ Then edit it accordingly.
*/

/* ---------------------------- Hardware Config ---------------------------- */

#define USB_CFG_IOPORTNAME      D
/* This is the port where the USB bus is connected. When you configure it to
 * "B", the registers PORTB, PINB and DDRB will be used.
 */
#define USB_CFG_DMINUS_BIT      3
/* This is the bit number in USB_CFG_IOPORT where the USB D- line is connected.
 * This may be any bit in the port.
 */
#define USB_CFG_DPLUS_BIT       2
/* This is the bit number in USB_CFG_IOPORT where the USB D+ line is connected.
 * This may be any bit in the port. Please note that D+ must also be connected
 * to interrupt pin INT0! [You can also use other interrupts, see section
 * "Optional MCU Description" below, or you can connect D- to the interrupt, as
 * it is required if you use the USB_COUNT_SOF feature. If you use D- for the
 * interrupt, the USB interrupt will also be triggered at Start-Of-Frame
 * markers every millisecond.]
 */
#define USB_CFG_CLOCK_KHZ       (F_CPU/1000)
/* Clock rate of the AVR in kHz. Legal values are 12000, 12800, 15000, 16000,
 * 16500, 18000 and 20000. The 12.8 MHz and 16.5 MHz versions of the code
 * require no crystal, they tolerate +/- 1% deviation from the nominal
 * frequency. All other rates require a precision of 2000 ppm and thus a
 * crystal!
 * Since F_CPU should be defined to your actual clock rate anyway, you should
 * not need to modify this setting.
 */
#define USB_CFG_CHECK_CRC       0
/* Define this to 1 if you want that the driver checks integrity of incoming
 * data packets (CRC checks). CRC checks cost quite a bit of code size and are
 * currently only available for 18 MHz crystal clock. You must choose
 * USB_CFG_CLOCK_KHZ = 18000 if you enable this option.
 */

/* ----------------------- Optional Hardware Config ------------------------ */

#define USB_CFG_PULLUP_IOPORTNAME   D
/* If you connect the 1.5k pullup resistor from D- to a port pin instead of
 * V+, you can connect and disconnect the device from firmware by calling
 * the macros usbDeviceConnect() and usbDeviceDisconnect() (see usbdrv.h).
 * This constant defines the port on which the pullup resistor is connected.
 */
#define USB_CFG_PULLUP_BIT          4
/* This constant defines the bit number in USB_CFG_PULLUP_IOPORT (defined
 * above) where the 1.5k pullup resistor is connected. See description
 * above for details.
 */

/* --------------------------- Functional Range ---------------------------- */
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

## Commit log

2019-12-30 Add leds
2019-12-30 Use our new USB VID/PID. Thanks to OpenMoko
2020-01-02 Use a static buffer when reading/writing to target device
2020-01-02 Add leds Reichelt item numbers
2020-01-05 enable U2X to increase baudrate resolution
    this also round up UBRR if needed, with some tricks to avoid doing float
    division
    [main.c]
2020-01-05 reset watchdog before set baudrate. increase watchdog timer to 2s
    [main.c]
2020-01-17 support reading fuses
2020-01-24 major rewrite
    - detect baudrate only during startup, measuring break bit width
    - removed some request types
    - reset device after returning an error
    schematics are outdated
    [main.c, usbconfig.h]
2020-01-29 re-added commands to detect baudrate and retrieve signature
    detecting baudrate during startup is hard to handle, lets allow clients
    to request baudrate detection themselves.
    also re-added command to get baudrate, because the detection is done
    after the usb request.
    warning: this implementation requires waiting for at least 4ms after
    requesting baudrate detection, before sending any other requests,
    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
2020-02-05 reset usart before detecting pulse width
    [main.c]
2020-02-05 add some context to error reporting
    [main.c]
2020-02-11 update schematics and prototype pictures
2020-02-12 update prototype pictures
2020-02-21 added minimal SPI support to allow setting fuses
    WARNING: this code does not work with current dwtk git master, and does
    not matches the schematics from this repository.
    [bits.h, main.c]
2020-02-21 allow to disable spi by releasing reset
    [main.c]
2020-02-22 regression: send break before reset
    [main.c]
2020-02-23 added SPI reset command
    [main.c]
2020-02-29 fixed wrong variable size
    [main.c]
2020-02-29 added capabilities support, to report if dw/spi is supported
2020-03-12 read usb serial number from eeprom if available.
    currently there's no easy way to write the data to eeprom, but if
    there's an 8 bytes string at the start of eeprom, it will be used as the
    serial number.
2020-06-28 fixed request length. error is not part of request
    [main.c]
2020-07-04 initial port to atmega88a
    this is not tested. need to build a prototype and validate.
2020-07-08 fix atmega88pa replacement for TIFR
    it provides a separated TIFR for timer 1
    [bits.h]
2020-07-09 do not implement fuses reading for attiny4313 debug builds
    this saves us some flash space, to allow us having debug builds for
    attiny4313. the software implementation in dwtk is fast enough for most
    use cases anyway.
2020-07-16 atmega88pa: increase SPI prescaler, to reduce frequency.
    the slower SPI frequency works fine for all the range of target MCU
    frequencies, while the old one would fail for slower target MCUs.
    [main.c]
2020-10-11 hardware: initial import of kicad schematics and pcbs
    [dwtk-ice-lite.kicad_pcb, dwtk-ice-lite.sch, dwtk-ice-mega.kicad_pcb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]
2020-10-14 hardware: update dwtk-ice-mega pcb values
    [dwtk-ice-mega.kicad_pcb]
2020-10-14 hardware: added mouser references
    [dwtk-ice-lite.sch, dwtk-ice-mega.sch, dwtk-ice.sch]
2021-01-05 usbconfig: fixed vendor name
    [usbconfig.h]
2022-01-07 support atmega{8,16,32}u2 native USB 2.0 devices
    [dwtk-ice-u2.kicad_pcb, dwtk-ice-u2.sch]
2022-01-07 actions: do not upload bom if not master or tag build
